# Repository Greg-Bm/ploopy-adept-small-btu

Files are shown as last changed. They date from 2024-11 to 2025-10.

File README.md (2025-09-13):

# ploopy-adept-small-btu

> [!TIP]
> Making these models take time and investment. I would like to keep them free, so if you like them, please consider to [buy me a coffee](https://www.paypal.com/donate/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)

A small Ploopy Adept case with BTU bearings

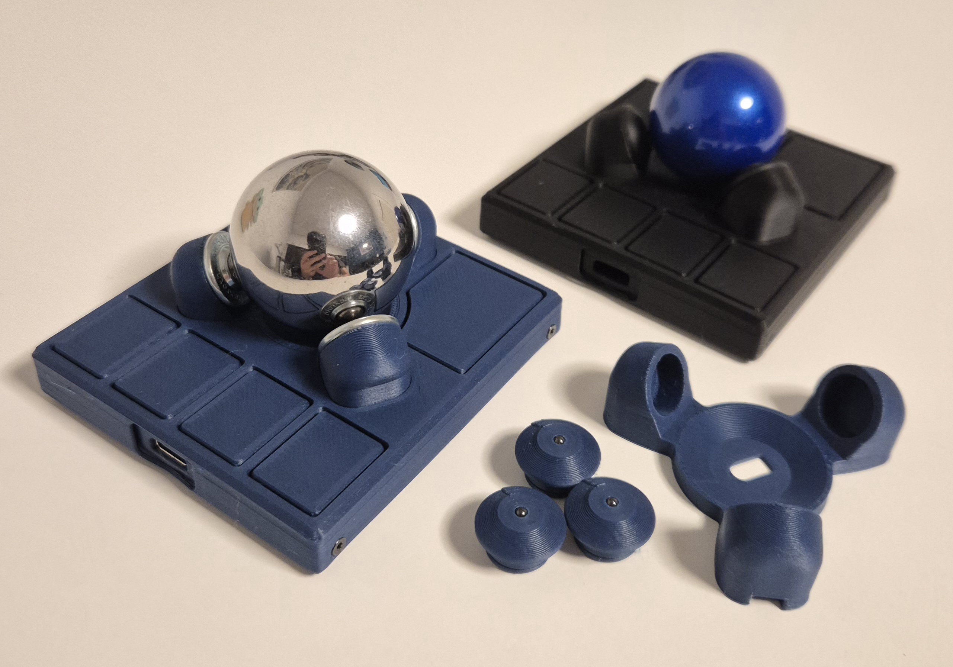
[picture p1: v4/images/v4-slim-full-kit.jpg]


I really like the Ploopy Adept hardware, but I wanted something smaller and lower to use between the two parts of my split keyboard. So I created this case for the Ploopy Adept, which is pretty small and low.

There are 4 versions:

- [V1](./v1-deprecated/): for a 34mm trackball. This is the initial version and it is deprecated. I would not recommend going for it. I am just keeping it here in case anyone still needs it. It will go at some point.

- [V2](./v2/): for a 38.1mm (1.5 inch) trackball. This version is still good to use and it can also fit the 34mm trackball support from V3.

- [V3](./v3/): which has trackball supports for both 34mm and 38.1mm trackballs. It is somewhat the same as V2, but with aesthetical improvements and slight improvements on the buttons too. In V3, the top and bottom of the case are the same, whether you choose to use a 34mm or a 38.1mm trackball, but you need to choose the correct track ball support.

- [V4 Slim](./v4/): which has trackball supports for both 34mm and 38.1mm trackballs. It is a much slimmer version of the v3, with aesthetical improvements e.g. all front buttons have the same size. The top and bottom of the case are the same, whether you choose to use a 34mm or a 38.1mm trackball, but you need to choose the correct track ball support.

I would obviously recommend going for the V4, but it is up to you to choose. You can find assembly instructions by browsing into the folder of each of the versions.

If you would like to user other bearings instead of BTUs, there are adapters available [here](https://github.com/adept-anyball/mod/tree/master/adapters).

Enjoy it! Feedback and contributions are very welcome.

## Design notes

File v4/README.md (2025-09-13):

# V4 - SLIM - 34mm and 38.1mm (1.5 inch) trackball


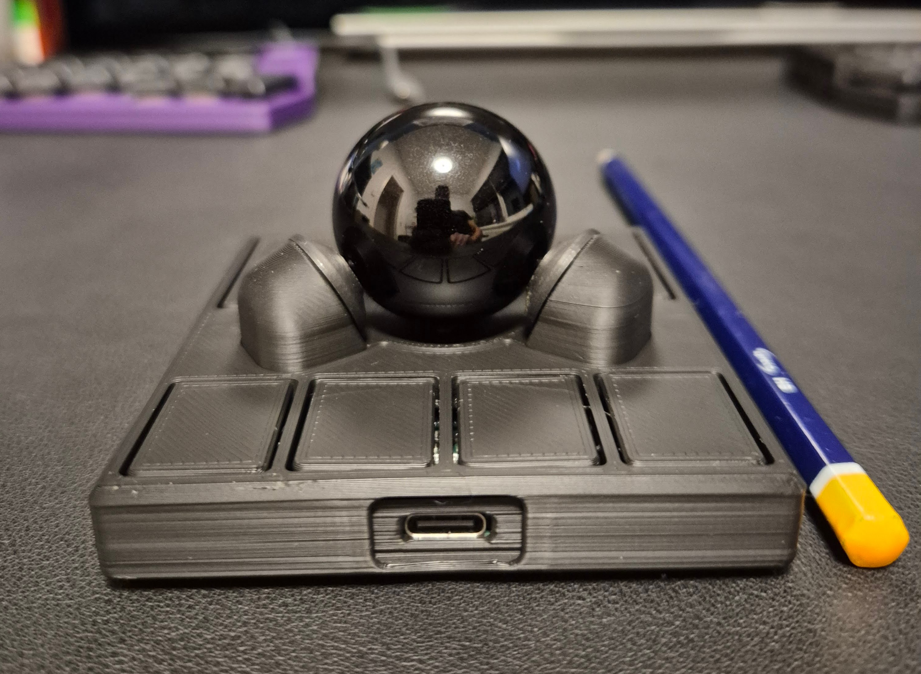
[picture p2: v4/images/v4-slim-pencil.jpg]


This design consists of 3 parts, see the mechanicals section for the explanation. It prints without supports and require minimal assembly.
Even though the top part consists of 2 separate parts, it looks like a unibody part after assembly.

## Mechanicals

1. v4-slim-top: the top frame with buttons and a cut-out for the track ball support insert (part #2)
2. v4-slim-38mm-trackball-support.step **OR** v4-slim-34mm-trackball-support.step: the trackball insert where the bearings and the trackball should be placed. It fits in the cut-out of the part #1. Choose the part the fits the trackball size that you want to use.
3. v4-slim-bottom: the bottom part of the case, where the pcb should be placed. The bottom has 4 sunken holes to optionally insert self-adhesive silicone bumpers of 8mm diameter and 1.6mm height.

## Printing instructions/remarks

**The models print without the need of any support. Using supports will likely ruin the print, unless you really know what you are doing!**

I have printed it in both PLA and PETG and both work fine. I have been using a 0.1mm layer height with good results.

- Part #1 should be printed with the buttons facing the build plate (so upside-down). and the remaining parts should be
- Part #2 and #3 should be printed in the regular orientation, which means with the flat part facing the build plate

## BoM

- [A Ploopy Adept kit](https://ploopy.co/shop/adept-trackball-full-kit/)
- 4 M2 x 10mm countersunk screws. I used [these ones](https://www.amazon.de/-/en/gp/product/B0D6QXRH6H/ref=ppx_od_dt_b_asin_title_s00?ie=UTF8&th=1)
- A trackball or the appropriate size:
  - 38mm (1.5 inch): I have used my Ploopy Nano trackball. You can either buy a billiard ball or something more fit for purpose like this ones from [gamingtrackball](https://www.gamingtrackball.com/products/yellow-and-silver-add-on-balls)
  - 34mm: I have used a Perixx 34mm trackball. You can find some different models [here](https://eu.perixx.com/collections/trackball)
- 3 BTU bearings [KU-B8-OFK R053010810](https://store.boschrexroth.com/BALL-TRANSFER-UNIT_R053010810?cclcl=en_MY) or 3 static bearings with adapters from [here](https://github.com/adept-anyball/mod/tree/master/adapters). I recommend using the \*-no-glue.step.
- (OPTIONAL) Self-adhesive silicone bumpers of 8mm diameter and 1.6mm height. Like [these ones](https://www.amazon.com/VOVOV-Small-Cabinet-Furniture-Bumpers/dp/B016GXAZOA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)

## Assembly

See Mechanicals section above for the part numbers.

1. Print all the parts
2. Insert the 3 bearings on part #2. There is some clearance, so you should not need to push very hard, only a bit of force is necessary.
3. Insert part #2 into the cut-out of part #1, making sure that the flat part of the optics cut-out is the round edge of the case (see picture below). Make sure that the bottom aligns perfectly. The part should stay in place, but you may choose to glue them together, if you prefer.

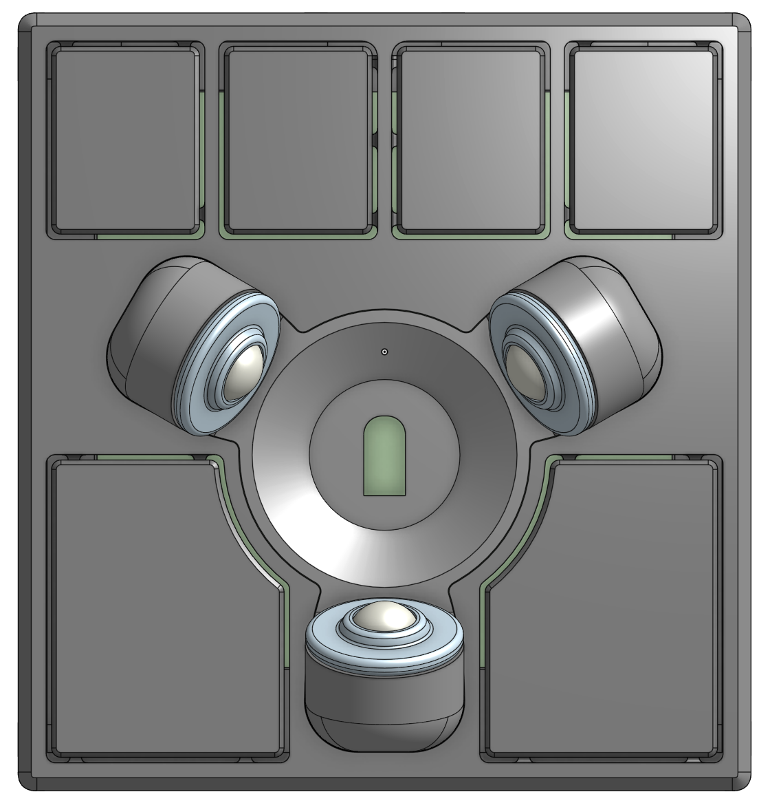
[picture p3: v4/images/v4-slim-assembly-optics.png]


4. Place the PCB in the sunken area of part #3
5. Place the top part over the bottom part making sure that the optics are aligned correctly. The top part should slide on top of the bottom and the holes on the side must align.
6. Fix the bottom to the top by screwing the M2 screws on the side. Start by screwing all the screws half in and then tighten them up. Do not screw too tight, just enough so the screws are flatten with the side.

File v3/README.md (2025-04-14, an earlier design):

# V3 - 34mm and 38.1mm (1.5 inch) trackball

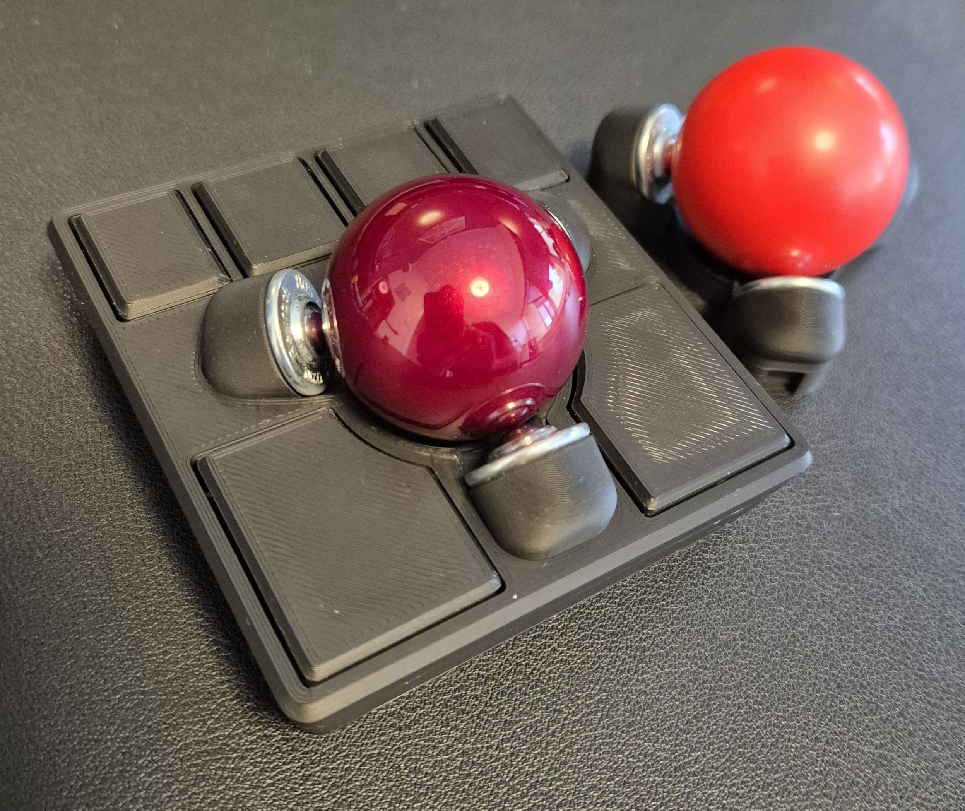
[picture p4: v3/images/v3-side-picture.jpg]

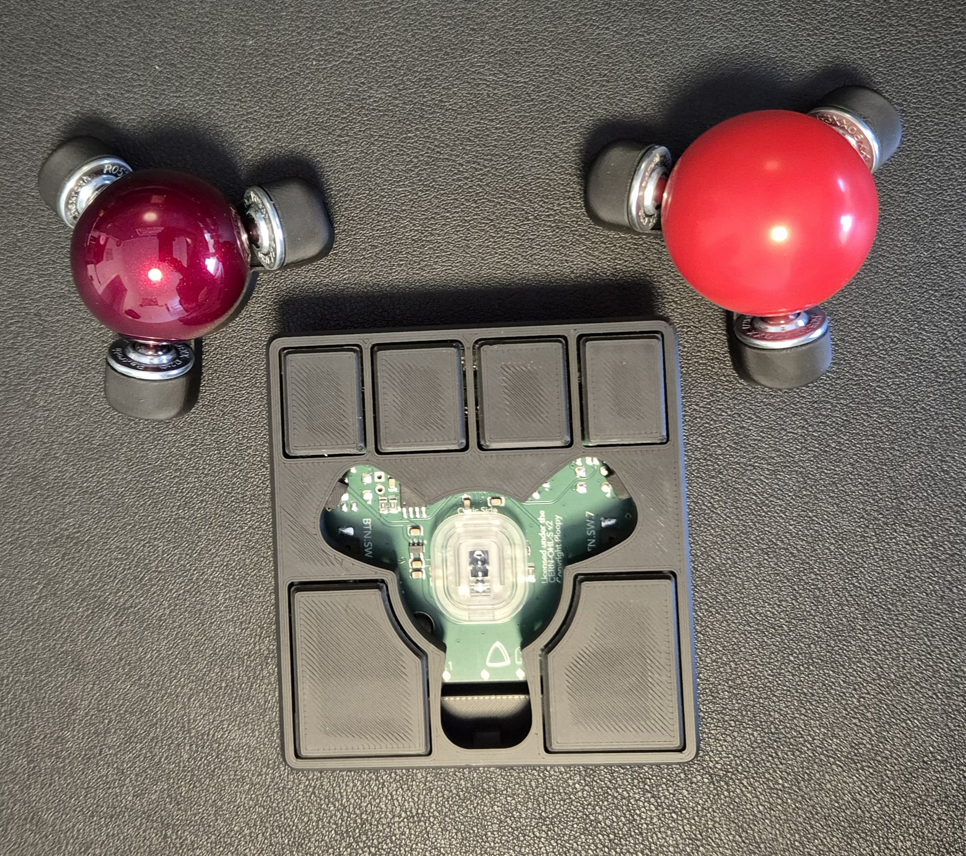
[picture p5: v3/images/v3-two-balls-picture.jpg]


This design consists of 4 parts, see the mechanicals section for the explanation. It prints without supports and require minimal assembly.
Even though the top part consists of 2 separate parts, it looks like a unibody part after assembly.

## Mechanicals

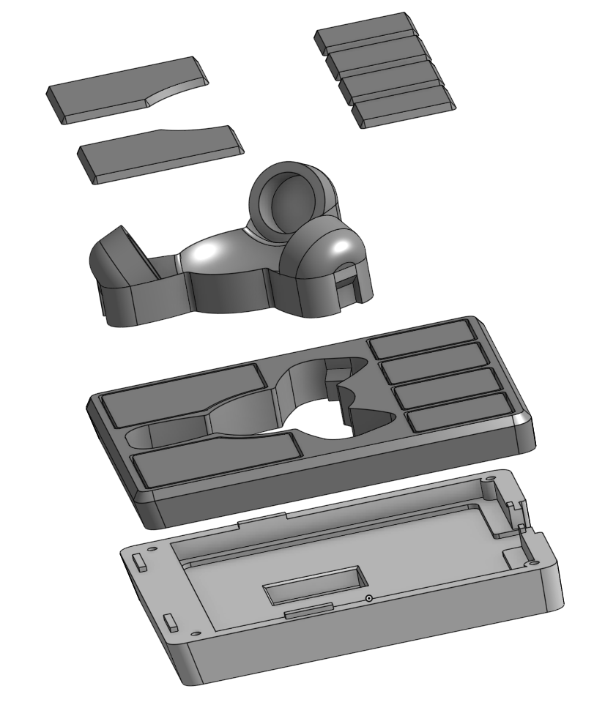
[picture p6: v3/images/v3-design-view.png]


1. v3-top-no-inserts.step **OR** v3-top.step: the top frame with buttons and a cut-out for the track ball support insert (part #2). If you choose the _no-inserts_ model, you won't need to use thread inserts, you can just screw the M2 screw directly into the case. However, if you do have the thread inserts at hand, I would recommend using them, since the print will last longer in case you disassemble it often.
2. v3-38mm-trackball-support.step **OR** v3-34mm-trackball-support.step: the trackball insert where the bearings and the trackball should be placed. It fits in the cut-out of the part #1. Choose the part the fits the trackball size that you want to use.
3. v3-bottom.step: the bottom part of the case, where the pcb should be placed. The bottom has 4 sunken holes to optionally insert self-adhesive silicone bumpers of 8mm diameter and 1.6mm height.
4. (OPTIONAL) v3-buttons.step: 1.5mm flat raised buttons. They should be glued to the case. I use them and I prefer both the looks and the ergonomics with them on.

## Printing instructions/remarks

**The models print without the need of any support. Using supports will likely ruin the print, unless you really know what you are doing!**

I have printed it in both PLA and PETG and both work fine. I have been using a 0.1mm layer height with good results.

- Part #1 should be printed with the buttons facing the build plate (so upside-down). and the remaining parts should be
- Part #2 and #3 should be printed in the regular orientation, which means with the flat part facing the build plate
- Part #4 can be printed in any orientation. I usually print with the top of the buttons facing the build plate, since I mostly use a smooth plate.

## BoM

- [A Ploopy Adept kit](https://ploopy.co/shop/adept-trackball-full-kit/)
- 4 M2 x 10mm countersunk screws. I used [these ones](https://www.amazon.de/-/en/gp/product/B0D6QXRH6H/ref=ppx_od_dt_b_asin_title_s00?ie=UTF8&th=1)
- A trackball or the appropriate size:
  - 38mm (1.5 inch): I have used my Ploopy Nano trackball. You can either buy a billiard ball or something more fit for purpose like this ones from [gamingtrackball](https://www.gamingtrackball.com/products/yellow-and-silver-add-on-balls)
  - 34mm: I have used a Perixx 34mm trackball. You can find some different models [here](https://eu.perixx.com/collections/trackball)
- 3 BTU bearings [KU-B8-OFK R053010810](https://store.boschrexroth.com/BALL-TRANSFER-UNIT_R053010810?cclcl=en_MY)
- (OPTIONAL) 4 M2 x 4mm thread inserts, if you choose to use the top with thread insert. I used [these ones](https://www.amazon.de/dp/B088QJG676/ref=pe_27091401_487027711_TE_SCE_dp_i1?th=1)
- (OPTIONAL) Self-adhesive silicone bumpers of 8mm diameter and 1.6mm height. Like [these ones](https://www.amazon.com/VOVOV-Small-Cabinet-Furniture-Bumpers/dp/B016GXAZOA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)
- (OPTIONAL) Superglue to put some of the parts together

## Assembly

See Mechanicals section above for the part numbers.

1. Print all the parts
2. (OPTIONAL) Glue part #4 to part #1
3. Insert the 3 BTU bearings on part #2. There is some clearance, so you should not need to push very hard, only a bit of force is necessary.
4. Insert part #2 into the cut-out of part #1, making sure that the flat part of the optics cut-out is the round edge of the case (see picture below). Make sure that the bottom aligns perfectly. The part should stay in place, but you may choose to glue them together, if you prefer.

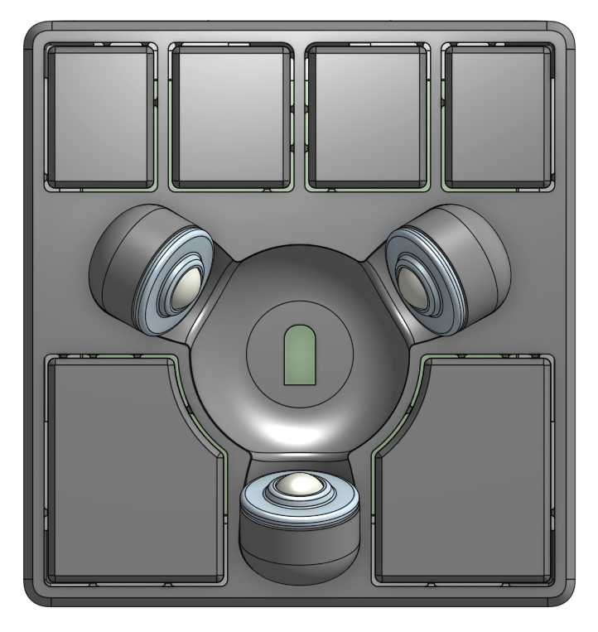
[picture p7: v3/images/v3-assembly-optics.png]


5. (OPTIONAL) Insert the 4 thread inserts in the 4 holes on the corners of the bottom of part #1, using a heat-insertion tool or a soldering iron. I would recommend a proper heat-insertion tool like [this one](https://www.amazon.de/dp/B0C5CC2QB9/ref=pe_27091401_487027711_TE_SCE_dp_i1), since these thread inserts are quite small
6. Place the PCB in the sunken area of part #3
7. Place the top part over the bottom part making sure that the optics are aligned correctly. The bottom part has some small guides that should help placing the top correctly and holding it in place.
8. Screw the bottom to the top. Start by screwing all the screws half in and then tighten them up.

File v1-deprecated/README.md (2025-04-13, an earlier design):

# V1 - 34mm trackball (deprecated)

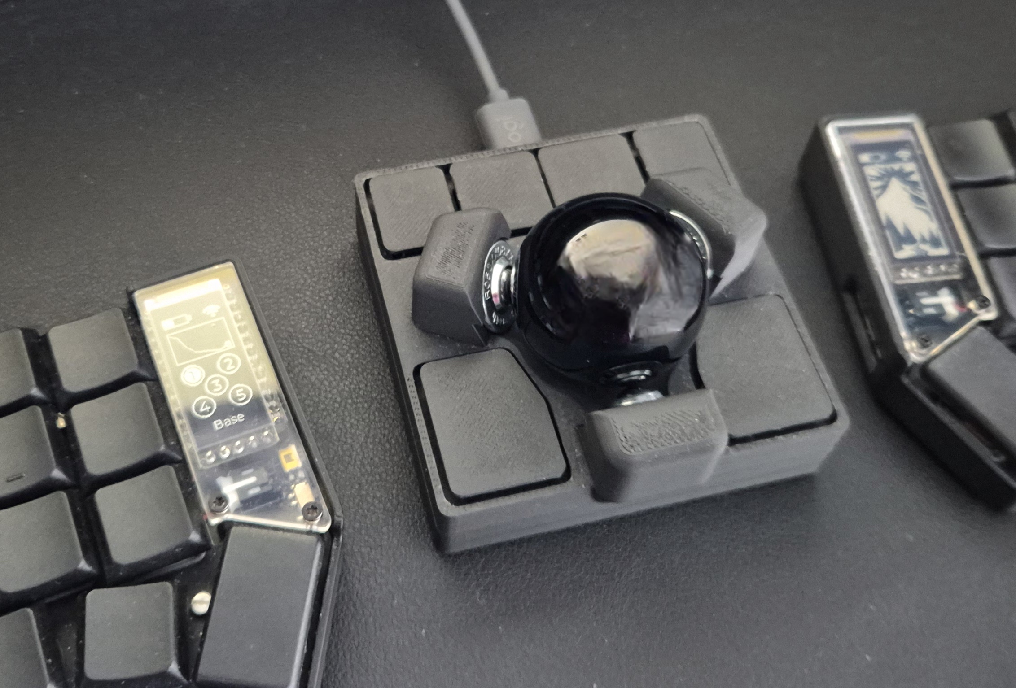
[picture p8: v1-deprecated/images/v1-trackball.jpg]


This is what I think is not great with this design and therefore I it is deprecated:

- The top part is a bit hard to print. I had originally designed the top part to snap on the bottom part, but then it would be even more difficult to print, so I went for a flat bottom. The best way I found to print the top part, in order to get a good finish, is to print it in the more regular position, meaning with the buttons up. I added supports and because of the small "springs" in the buttons, you need to be very patient to remove the supports without damaging the buttons.

- The spring mechanisms on the front buttons are not super flexible, so in the beginning the 4 front buttons may feel a bit hard to press, but it gets better as you use. There are also small "dead-spots" on the buttons which would be nice to fix, but nothing that have bothered me.

If you do improvements, please do submit a PR :)

## Mechanicals

There are 3 files: v1-top, v1-bottom and usb-insert. The usb-insert is a very small piece that you can insert on the bottom part after you have placed the pcb, as shown below:

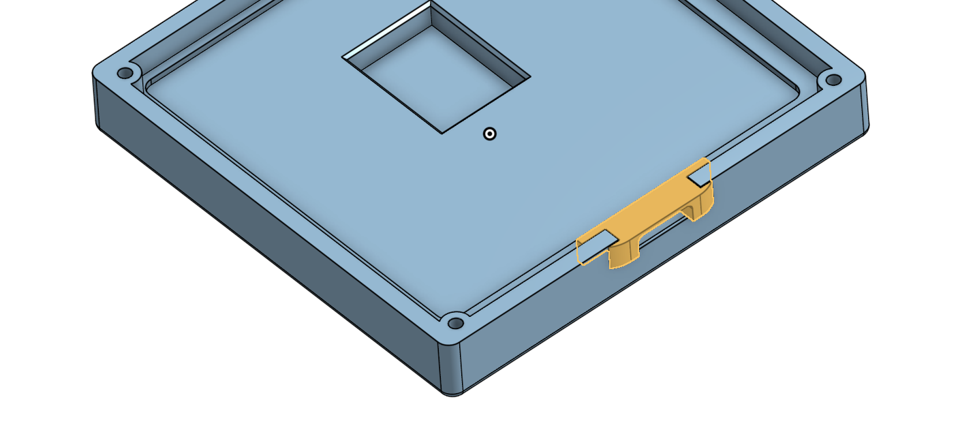
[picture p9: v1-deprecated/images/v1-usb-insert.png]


## BoM

- [A Ploopy Adept kit](https://ploopy.co/shop/adept-trackball-full-kit/)
- 4 M2 x 4mm thread inserts. I used [these ones](https://www.amazon.de/dp/B088QJG676/ref=pe_27091401_487027711_TE_SCE_dp_i1?th=1)
- 4 M2 x 10mm countersunk screws. I used [these ones](https://www.amazon.de/-/en/gp/product/B0D6QXRH6H/ref=ppx_od_dt_b_asin_title_s00?ie=UTF8&th=1)
- A 34mm trackball. I got mine at [Perixx](https://eu.perixx.com/collections/trackball/products/peripro-303)
- 3 BTU bearings [KU-B8-OFK R053010810](https://store.boschrexroth.com/BALL-TRANSFER-UNIT_R053010810?cclcl=en_MY)

## Assembly

1. Print all the parts and remove evt. supports very carefully from the top part, and avoid damaging the spring mechanisms of the buttons. I would recommend studying the top part a bit, so you get to know where you need to be careful.
2. Insert the 4 thread inserts in the 4 holes on the corners of the bottom of the top part, using a heat-insertion tool or a soldering iron. I would recommend a proper heat-insertion tool like [this one](https://www.amazon.de/dp/B0C5CC2QB9/ref=pe_27091401_487027711_TE_SCE_dp_i1), since these thread inserts are quite small
3. Insert the 3 BTU bearings on the top of the top part. There is some clearance, so you should not need to push very hard, only a bit of force is necessary. If the bearing do not insert easily, make sure to remove evt. material rests from supports and don't apply unnecessary force, which may end up damaging the top part.
4. Place the PCB in the sunken area of the bottom part
5. Place the USB-insert in the USB opening. It should just slide in.
6. Place the top part over the bottom part making sure that the optics are aligned correctly
7. Screw the bottom to the top. Start by screwing all the screws half in and then tighten them up.

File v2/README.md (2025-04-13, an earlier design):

# V2 - 38.1mm trackball (1.5 inch)



This design consists of 4 parts, see the mechanicals section for the explanation. It prints without supports and require minimal assembly.
Even though the top part consists of 2 separate parts, it looks like a unibody part after assembly.

## Mechanicals

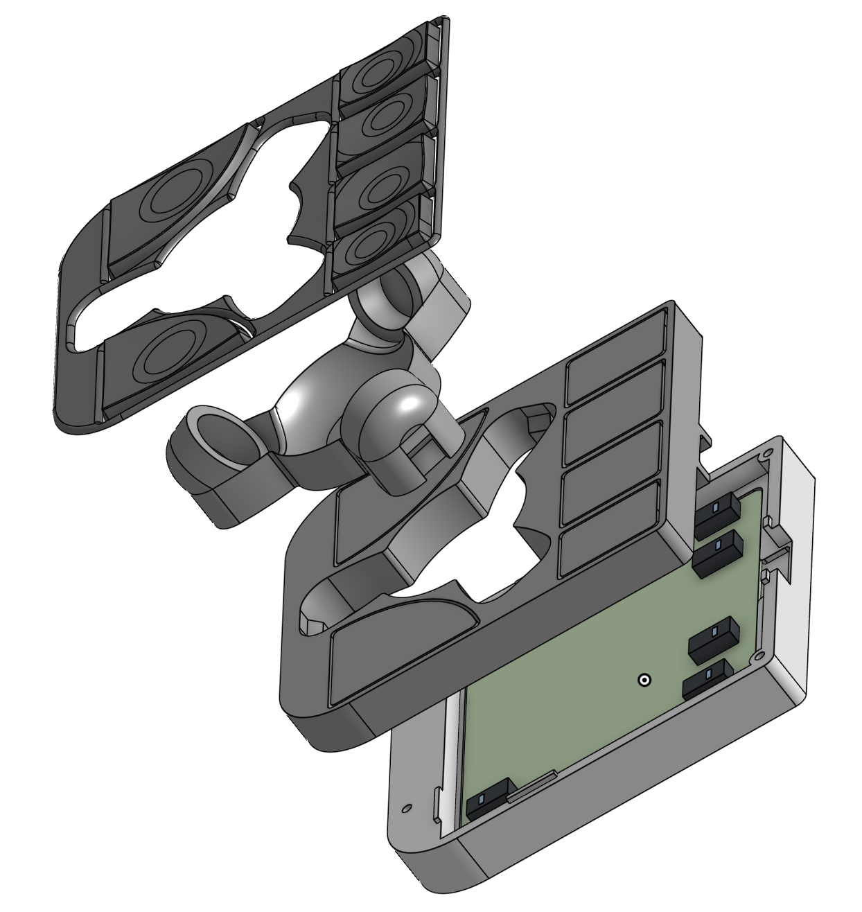
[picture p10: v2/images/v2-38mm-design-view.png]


1. v2-38mm-top-buttons.step: the top frame with buttons and a cut-out for the track ball support insert (part #2)
2. v2-38mm-top-trackball.step: the trackball insert where the bearings and the trackball should be placed. It fits in the cut-out of the part #1
3. v2-38mm-bottom.step: the bottom part of the case, where the pcb should be placed
4. (OPTIONAL) v2-38mm-cover-keycaps.step: a cover to the top, so you can add another finish to the top of the trackball and keycaps. These can be printed in different colors for some extra personalization and/or with a smaller layer height for a smoother surface :)

## Printing instructions/remarks

**The models print without the need of any support. Using supports will likely ruin the print, unless you really know what you are doing!**

I have printed it in both PLA and PETG and both work fine. I have been using a 0.1mm layer height with good results.

Part #1 should be printed with the buttons facing the build plate (so upside-down), and the remaining parts should be printed in the regular orientation.

## BoM

- [A Ploopy Adept kit](https://ploopy.co/shop/adept-trackball-full-kit/)
- 4 M2 x 4mm thread inserts. I used [these ones](https://www.amazon.de/dp/B088QJG676/ref=pe_27091401_487027711_TE_SCE_dp_i1?th=1)
- 4 M2 x 10mm countersunk screws. I used [these ones](https://www.amazon.de/-/en/gp/product/B0D6QXRH6H/ref=ppx_od_dt_b_asin_title_s00?ie=UTF8&th=1)
- A 38.1mm trackball (1.5 inch). I have used my Ploopy Nano trackball. You can either buy a billiard ball or something more fit for purpose like this ones from [gamingtrackball](https://www.gamingtrackball.com/products/yellow-and-silver-add-on-balls)
- 3 BTU bearings [KU-B8-OFK R053010810](https://store.boschrexroth.com/BALL-TRANSFER-UNIT_R053010810?cclcl=en_MY)
- (OPTIONAL) Superglue to put some of the parts together

## Assembly

See Mechanicals section above for the part numbers.

1. Print all the parts
2. (OPTIONAL) Glue part #4 to part #1
3. Insert the 3 BTU bearings on part #2. There is some clearance, so you should not need to push very hard, only a bit of force is necessary.
4. Insert part #2 into the cut-out of part #1, making sure that the flat part of the optics cut-out is the round edge of the case (see picture below). Make sure that the bottom aligns perfectly. The part should stay in place, but you may choose to glue them together, if you prefer.

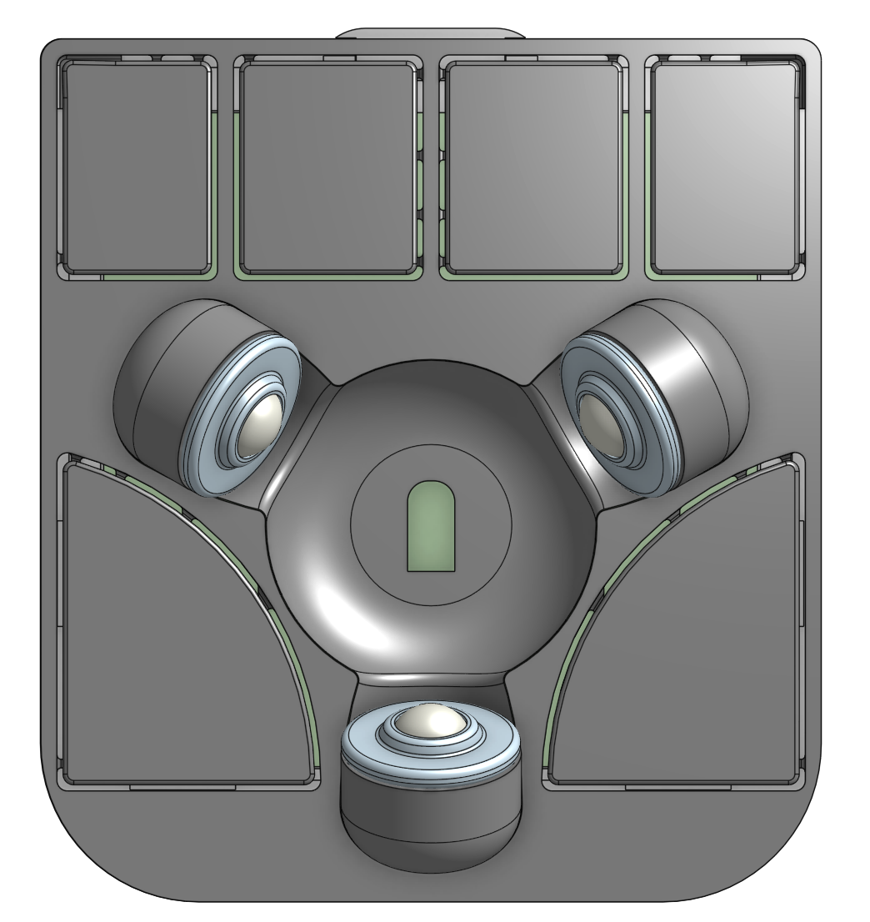
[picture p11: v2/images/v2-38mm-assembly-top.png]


5. Insert the 4 thread inserts in the 4 holes on the corners of the bottom of part #1, using a heat-insertion tool or a soldering iron. I would recommend a proper heat-insertion tool like [this one](https://www.amazon.de/dp/B0C5CC2QB9/ref=pe_27091401_487027711_TE_SCE_dp_i1), since these thread inserts are quite small
6. Place the PCB in the sunken area of part #3
7. Place the top part over the bottom part making sure that the optics are aligned correctly. The bottom part has some small guides that should help placing the top correctly and holding it in place.
8. Screw the bottom to the top. Start by screwing all the screws half in and then tighten them up.

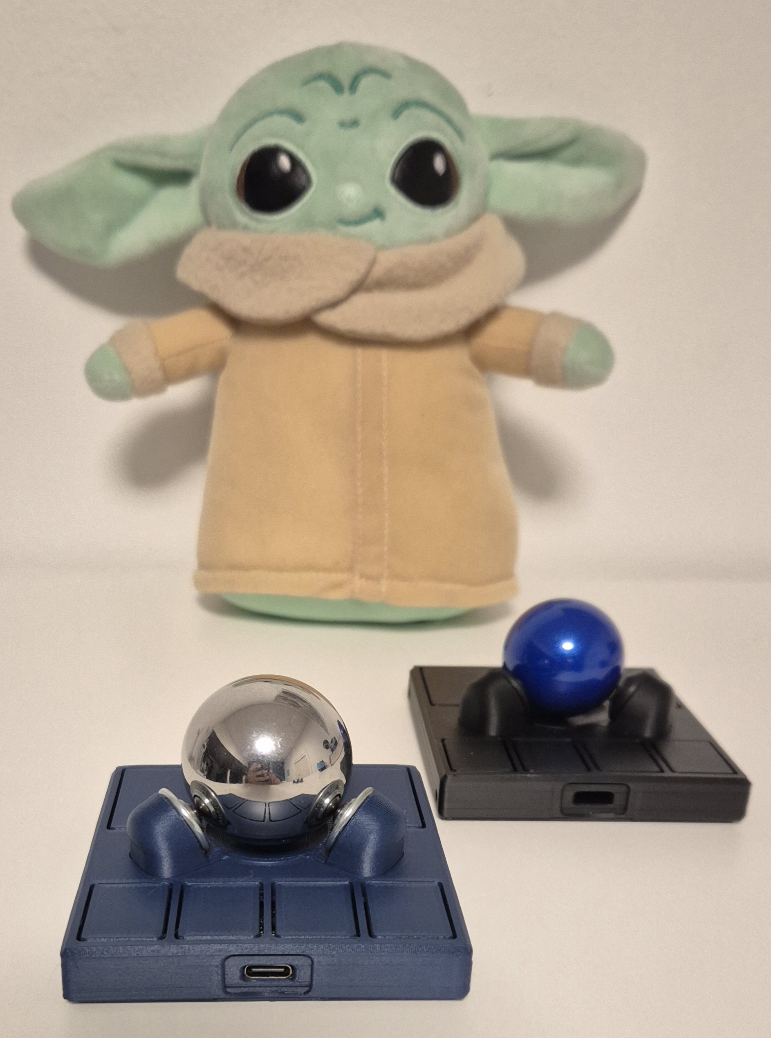
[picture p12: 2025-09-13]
v4/images/v4-slim-yoda.jpg

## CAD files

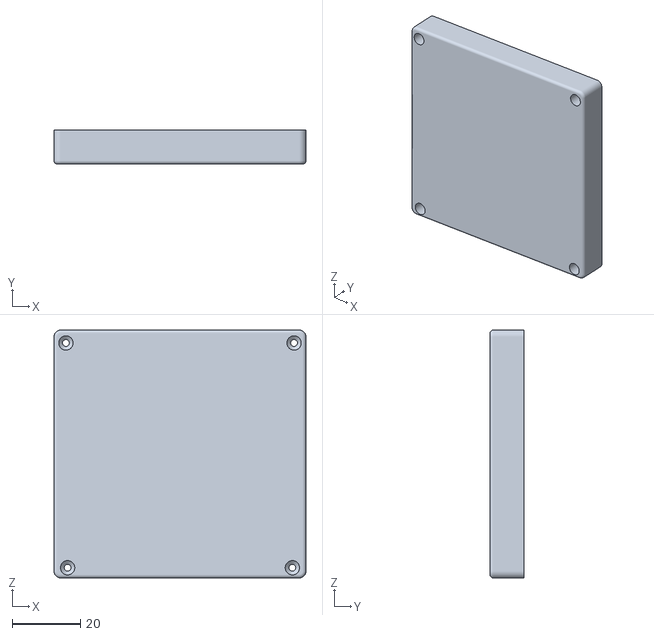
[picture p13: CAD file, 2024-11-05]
mechanicals/34mm/bottom.stl
74.0 x 10.0 x 72.8

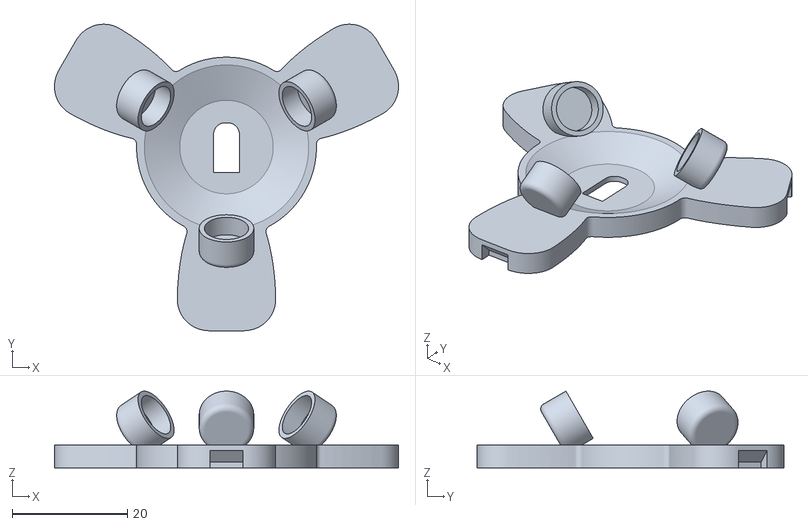
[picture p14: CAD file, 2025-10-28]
v4/generation script/trackball support generator- veichu btu, 25mm ball.stl
59.8 x 53.3 x 13.4

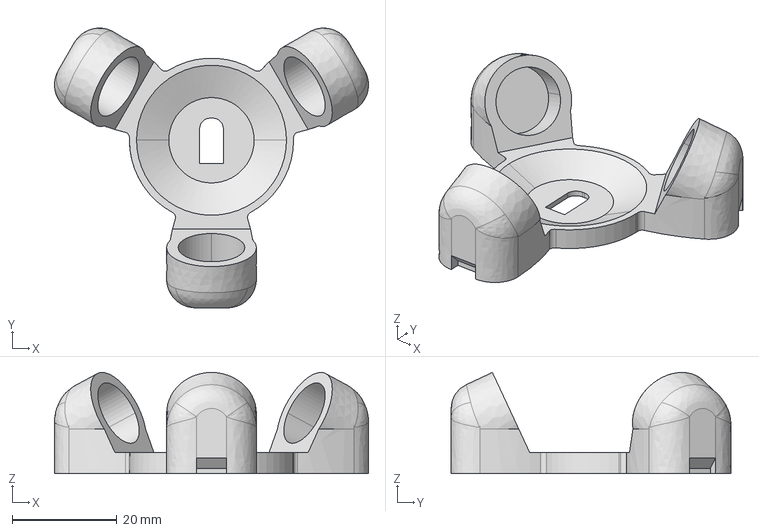
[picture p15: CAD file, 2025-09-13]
v4/v4-slim-34mm-trackball-support.step
59.8 x 53.3 x 19.3 mm

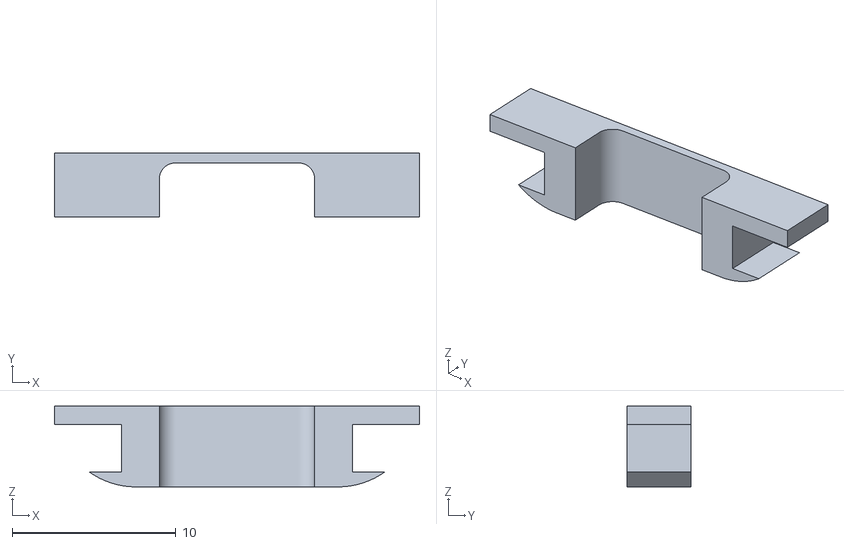
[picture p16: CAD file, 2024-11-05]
mechanicals/34mm/usb-insert.stl
22.3 x 3.90 x 4.94

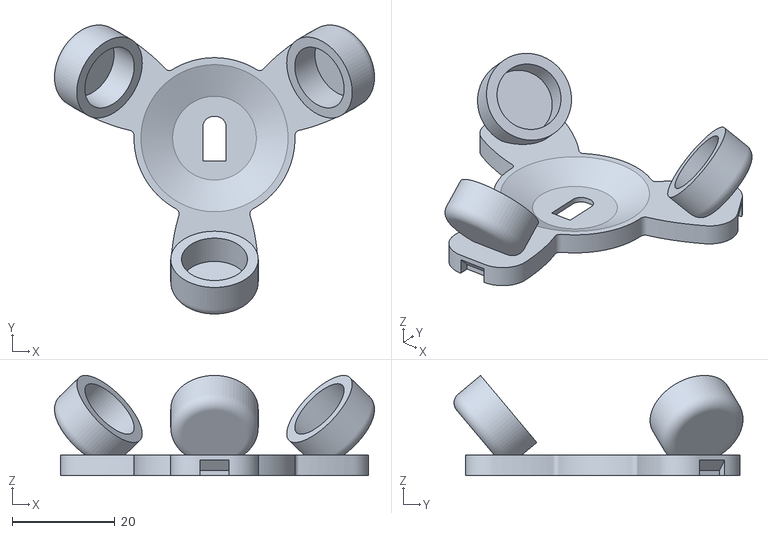
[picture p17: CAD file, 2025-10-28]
v4/generation script/trackball support generator - bosch btu 40mm ball.stl
62.2 x 56.1 x 19.5

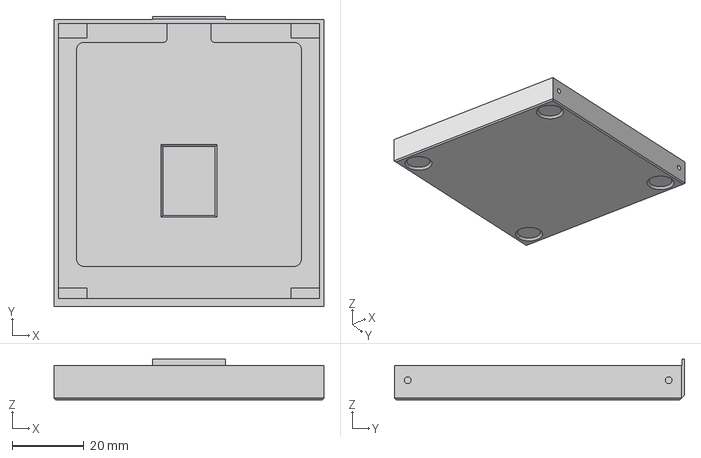
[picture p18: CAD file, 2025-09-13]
v4/v4-slim-bottom.step
75.2 x 80.8 x 11.4 mm

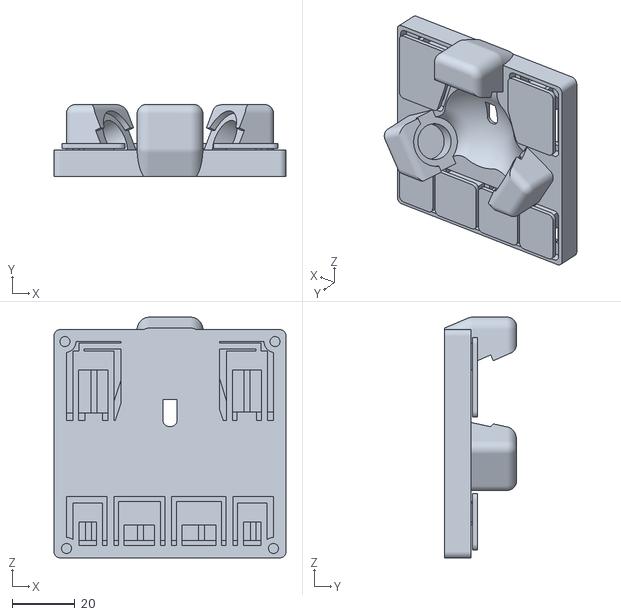
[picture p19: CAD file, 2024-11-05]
mechanicals/34mm/top.stl
74.0 x 23.0 x 76.8

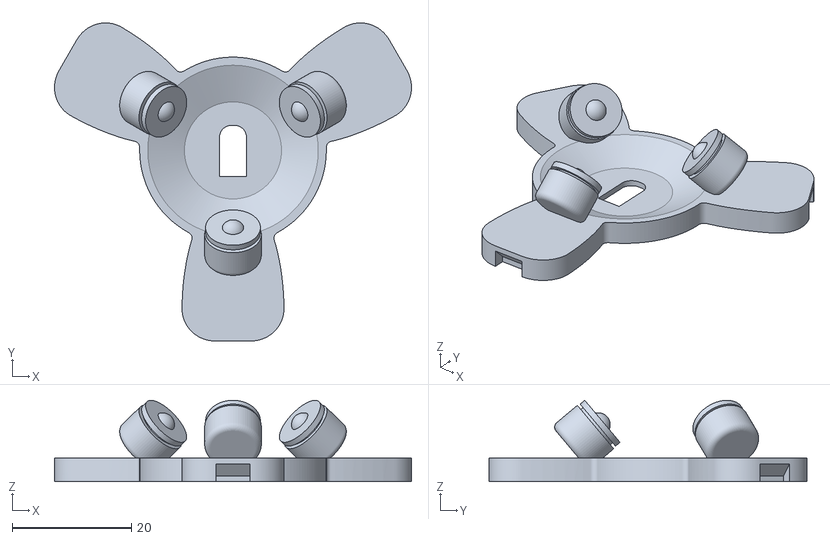
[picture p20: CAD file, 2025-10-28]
v4/generation script/trackball support generator- veichu btu builtin, 25mm ball.stl
59.8 x 53.3 x 13.6

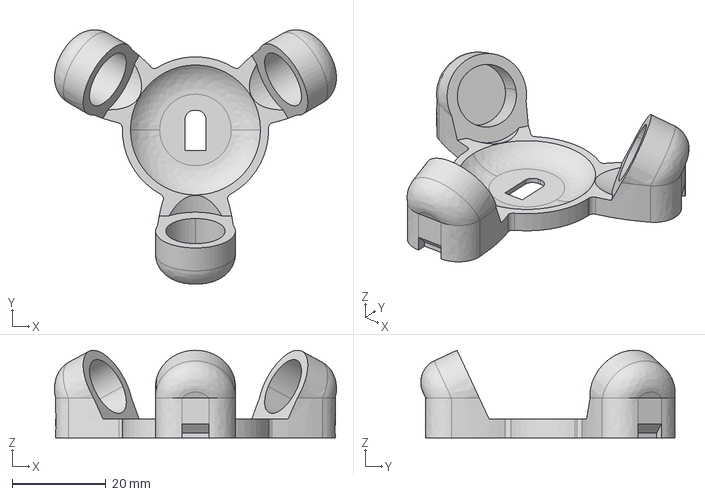
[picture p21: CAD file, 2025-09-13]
v4/v4-slim-38mm-trackball-support.step
60.3 x 54.4 x 18.7 mm

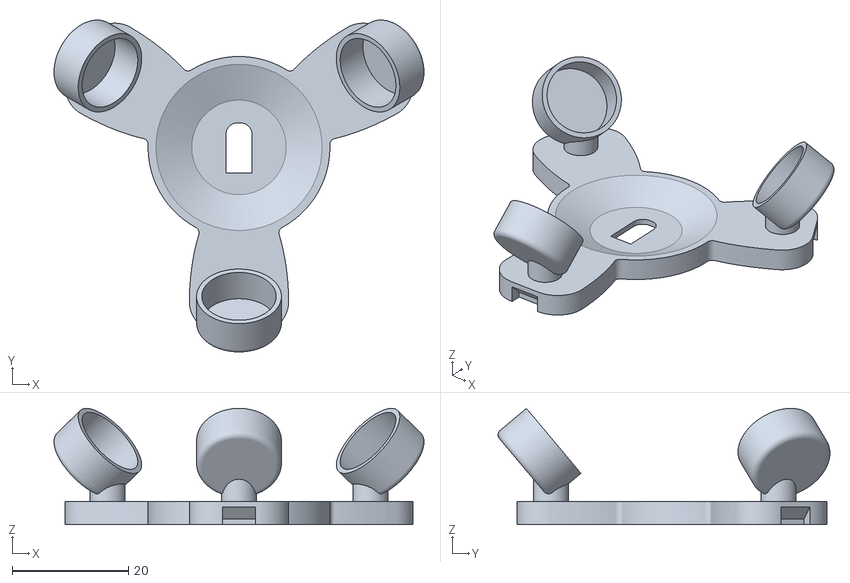
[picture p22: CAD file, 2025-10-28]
v4/generation script/trackball support generator - bosch 44.45mm.stl
63.6 x 57.1 x 20.0

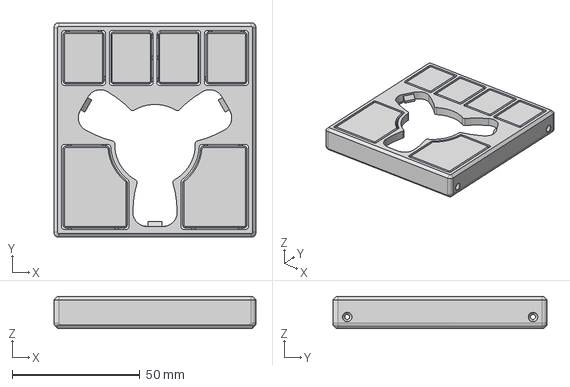
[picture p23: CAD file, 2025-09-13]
v4/v4-slim-top.step
79.0 x 83.8 x 12.7 mm

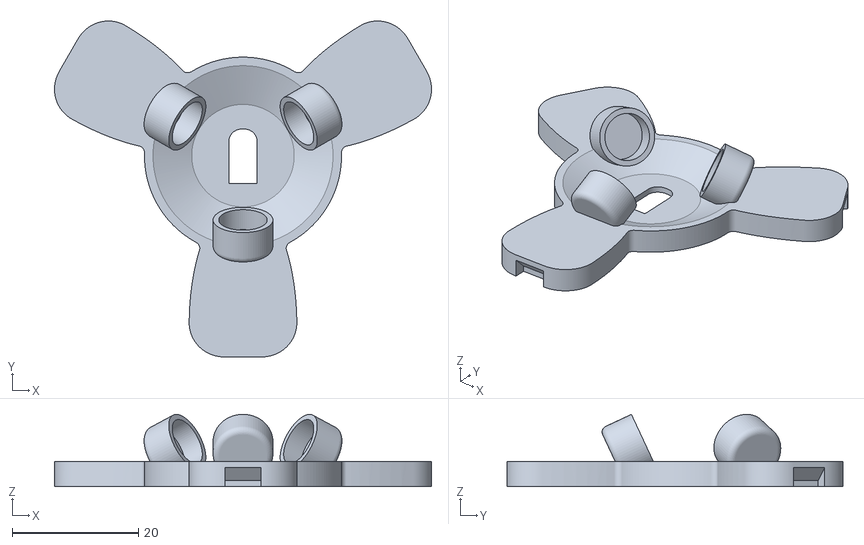
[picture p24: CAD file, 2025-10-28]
v4/generation script/trackball support generator - veichu btu, point63in.stl
59.8 x 53.3 x 11.5

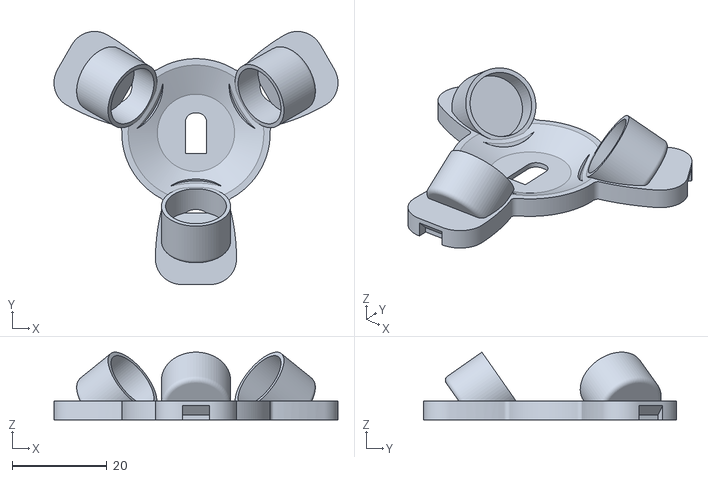
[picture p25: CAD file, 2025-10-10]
v4/generation script/trackball support generator - bosch btu, 21.8mm deflected.stl
59.8 x 53.3 x 14.3

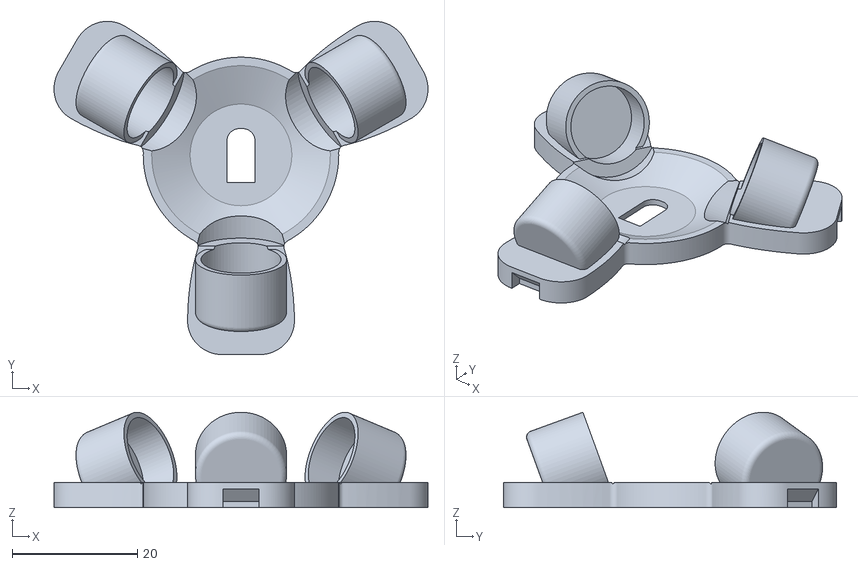
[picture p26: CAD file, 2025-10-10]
v4/generation script/trackball support generator - bosch btu, 25mm ball.stl
59.8 x 53.3 x 15.3

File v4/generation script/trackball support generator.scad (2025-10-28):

// this openscad file lets you generate supports for trackballs of various sizes. it also supports several different types of btus, e.g. bosch and veichu.

// units for americans
INCH = 25.4;


// support column parameter. for large balls
add_support_columns=true;
suph = 10; // height
supr = 4; // radius
supfwd = 3; // forward


// Global resolution
$fs = 0.1;  // Don't generate smaller facets than 0.1 mm
$fa = 5;    // Don't generate larger angles than 5 degrees

// extra gap for the cup.
cup_tolerance = 0.1;

// space between btu brim and cup rim.
// can be useful if you want to be able to pry btus out easily.
brim_rim_gap = 0.5;

// btu cups will be cut off at and below this level.
cup_floor=0;

// raw dimensions of the btu.
// dimensions names like those for bosch rexroth R053010810: https://store.boschrexroth.com/en/us/p/ball-transfer-unit-r053010810
// for other btus, derive the dimensions corresponding to those for the bosch btu.

// bosch rexroth 
btu_H = 11.2;
btu_h = 4.8;
btu_D = 12.6;
btu_D1 = 17;
btu_dw = 7.938;
btu_a = 1.9;

// veichu 7.5mm. 
//btu_H = 6.1;
//btu_h = 2.1;
//btu_D = 7.5;
//btu_D1 = 9;
//btu_dw = 4;
//btu_a = 1;

// raw dimensions for tracking ball
ball_d = 52;
ball_e = 2;

// angle of btus. adjust as needed.
phi = 70;

// how much the btu housing points down.
deflection = 15;

// extra space in front of btu rim. adjust as needed.
btu_clearance = ball_d/2;


//thickness of btu cup walls. adjust as needed.
holder_side_wall=1;//(btu_D1 - btu_D)/2;
holder_back_wall=2;


// derived btu dimensions
btu_rw = btu_dw/2;
btu_Hd = btu_H - btu_h;

// derived dimensions for tracking ball
ball_r = ball_d/2;
ball_h = ball_e + ball_r;


// unit vectors.
vx = [1,0,0];
vy = [0,1,0];
vz = [0,0,1];


module rb_cylinder(r,h,c){
    hull() {
        translate([0,0,c])cylinder(r=r,h=h-c);
        translate([0, 0, c]) rotate_extrude() translate([r-c, 0]) circle(r=c);
}   
}


module orig() {
    translate([0,11.1,-29.5]){
        import("../v4-slim-34mm-trackball-support.stl");}
}


module base(){
difference () {
    orig();
    union(){
    translate([0,0,4])
        cylinder(r=40, h=20);
//    translate([0,0,2])
//        cylinder(r=27, h=21);
}
}

}

// virtual ball
translate(ball_h * vz)
    %sphere(r=ball_r);

module virtual_btu_atzero(clearance=0){
    sphere(r=btu_rw);
    translate(vz*(btu_rw - btu_H))
        cylinder(h=btu_Hd, r=(btu_D)/2 + cup_tolerance);
    translate(vz*(btu_rw - btu_h))
        cylinder(h=btu_a + clearance, r=(btu_D1)/2 + cup_tolerance);
}

module virtual_btu(clearance=0){
translate(ball_h * vz) rotate(-phi * vx) translate(-(ball_r + btu_rw)*vz) rotate(deflection * vx) virtual_btu_atzero(clearance);
}

module btu_holder_atzero(){
    translate((btu_rw - btu_H - holder_back_wall)*vz)
        rb_cylinder(h=btu_Hd + holder_back_wall - brim_rim_gap, r=btu_D/2 + holder_side_wall, c=holder_side_wall);
}

module btu_holder(){
    translate(ball_h * vz) rotate(-phi * vx) translate(-(ball_r + btu_rw)*vz) rotate(deflection * vx) btu_holder_atzero();
}

module btu_holders(){
   for(t=[0:120:359])rotate(vz*t)btu_holder();
}

module virtual_btus(clearance=0){
    for(t=[0:120:359])rotate(vz*t)virtual_btu(clearance);
}

module filler(){
    for(t=[0:120:359])rotate(vz*t)translate(-23*vy+2*vz)cube([10,10,4], center=true);
}

module below(h){
    translate(h*vz)rotate(vy*180)cylinder(r=60,h=60);
}


back = sin(phi) * (ball_r + btu_rw) + sin(phi - deflection) * (btu_H - btu_rw) + sin(phi - deflection - 90) * (btu_D/2);
module cup_support(){
    translate((supfwd - back)*vy+4*vz) cylinder(r=supr, h=suph);
}
module cup_supports(){
    for(t=[0:120:359])rotate(vz*t)cup_support();
}

color("grey")
difference(){
    union(){
        base();
        difference(){
        btu_holders();
            below(cup_floor);
        }
        if (add_support_columns)
        cup_supports();
        filler();
    }
    union(){
        virtual_btus(clearance=btu_clearance);
    }
}
%virtual_btus();

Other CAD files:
v2/v2-38mm-top-trackball.step
v3/v3-bottom.step
v2/v2-38mm-bottom.step
v2/v2-38mm-cover-keycaps.step
v2/v2-38mm-top-buttons.step
v3/v3-34mm-trackball-support.step
v3/v3-38mm-trackball-support.step
v3/v3-buttons.step
v3/v3-top-no-inserts.step
v3/v3-top.step
v4/v4-slim-34mm-trackball-support.stl
v4/v4-slim-38mm-trackball-support.stl
v4/v4-slim-bottom.stl
v4/v4-slim-top.stl

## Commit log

2024-11-05 feat: add stls and readme
    [bottom.stl, top.stl, usb-insert.stl]
2025-01-04 feat: add 38mm trackball instructions and files
    Also reorganize the repo
    [38mm-bottom.step, 38mm-top-buttons.step, 38mm-top-trackball.step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]
2025-01-04 feat: add keycaps and cover
    [38mm-cover-keycaps.step]
2025-01-05 feat: improve design by removing usb-insert part and better cover part
    [38mm-bottom.step, 38mm-cover-keycaps.step, 38mm-top-buttons.step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]
2025-04-13 feat: add v3 model and update everything
    [usb-insert.stl, v1-34mm-bottom.stl, v1-34mm-top.stl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]
2025-04-14 feat: update v3 bottom
    [v3-bottom.step]
2025-09-13 feat: add v4 slim version
    [v4-slim-34mm-trackball-support.step, v4-slim-34mm-trackball-support.stl, v4-slim-38mm-trackball-support.step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]
2025-10-10 generator script
    [trackball support generator.scad]
2025-10-10 example stl
    [trackball support generator - bosch btu, 25mm ball.stl]
2025-10-10 added deflection parameter
    [trackball support generator - bosch btu, 25mm deflected.stl, trackball support generator.scad]
2025-10-10 added cup floor parameter
    [trackball support generator.scad]
2025-10-10 name fix
    [trackball support generator - bosch btu, 21.8mm deflected.stl]
2025-10-28 updated gen script and added a few more generated stl files
    [trackball support generator - bosch 44.45mm.stl, trackball support generator - bosch btu 40mm ball.stl, trackball support generator - veichu btu, point63in.stl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]
